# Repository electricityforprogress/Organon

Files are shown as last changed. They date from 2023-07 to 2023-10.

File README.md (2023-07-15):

# Organon
Biodata for Eurorack
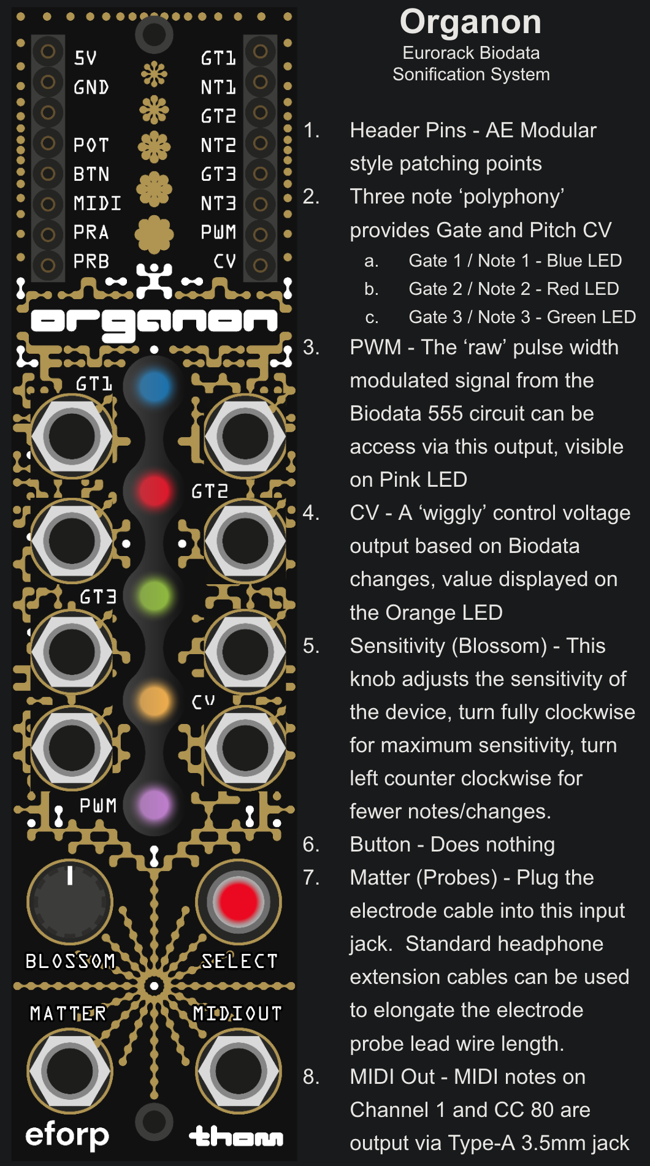
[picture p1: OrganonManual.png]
Organon Biodata Sonification System


This device can connect to the leaves of a plant and produces three pairs of Note CV and Gate signals, along with outputs for the 'raw' PWM Biodata square wave, a 'wiggly' CV output, and MIDI out!  The Organon comes with a set of snap electrode leads and three pairs of sticky pads. 
Using an Arduino Pro Micro 32u4, LMC555 timer, and a MC4728 Quad DAC this device was quite hard to find parts for until late 2023.

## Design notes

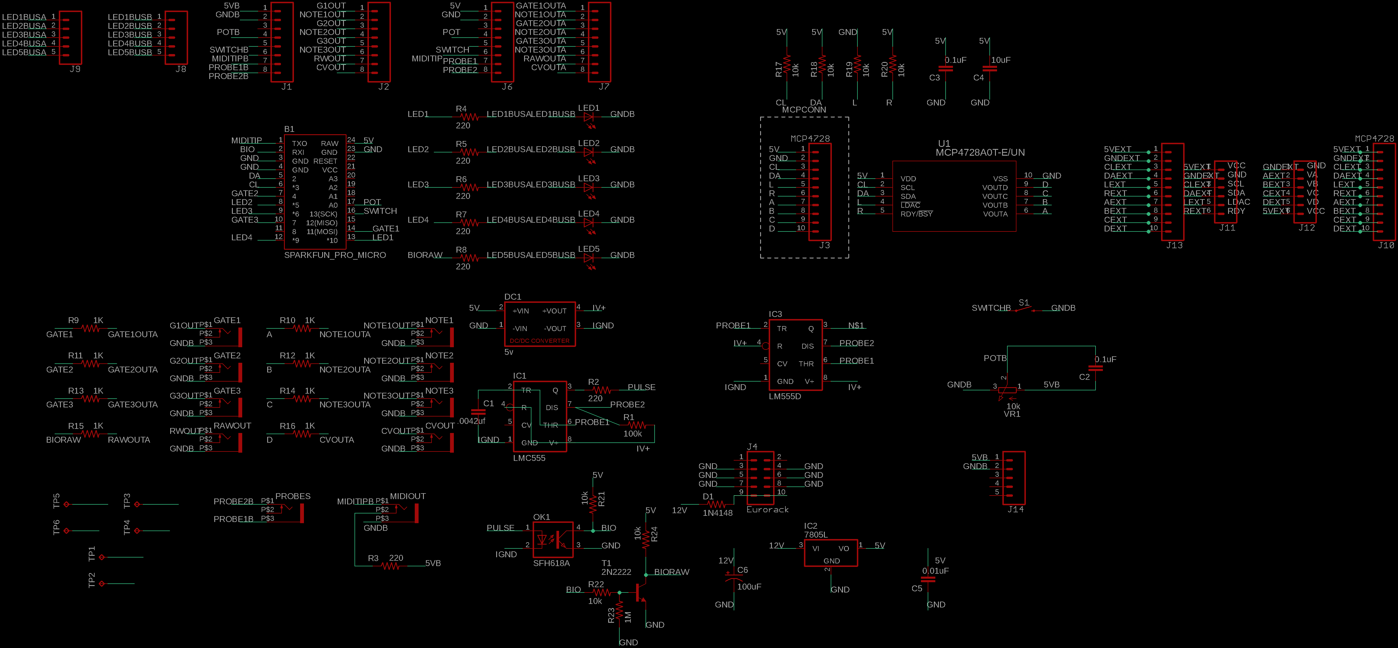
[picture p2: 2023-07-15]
Organon_Schematic.png

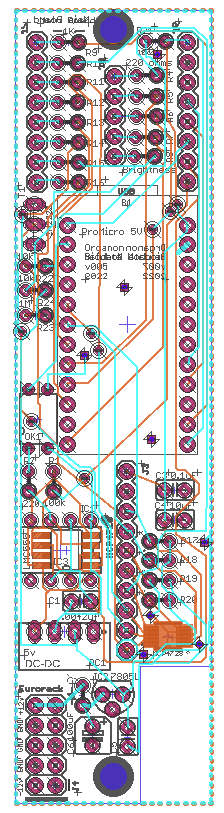
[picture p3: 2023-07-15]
BrainBoard007.png

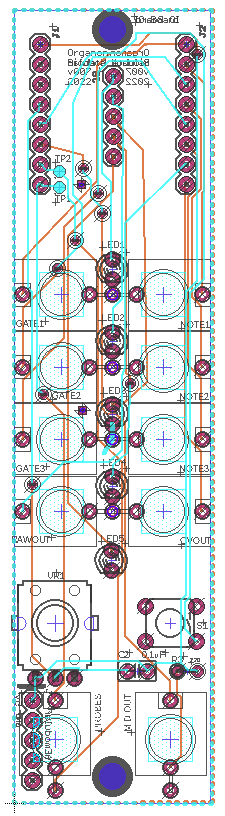
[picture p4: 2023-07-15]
IOBoard007.png

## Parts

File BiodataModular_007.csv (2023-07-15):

Part | Value | Device | Package | Description | MANUFACTURER_PART_NUMBER | MF | MPN | OC_FARNELL | OC_NEWARK | PROD_ID | SF_ID | SF_SKU | TP_SIGNAL_NAME | VENDOR
B1 | SPARKFUN_PRO_MICRO | SPARKFUN_PRO_MICRO | SPARKFUN_PRO_MICRO | SparkFun Pro Micro
C1 | .0042uf | C2.5/2 | C2.5-2 | CAPACITOR
C2 | 0.1uF | C2.5/2 | C2.5-2 | CAPACITOR
C3 | 0.1uF | C2.5/2 | C2.5-2 | CAPACITOR
C4 | 10uF | C2.5/2 | C2.5-2 | CAPACITOR
C5 | 0.01uF | C2.5/2 | C2.5-2 | CAPACITOR
C6 | 100uF | CPOL-USB45181A | B45181A | POLARIZED CAPACITOR, American symbol
CVOUT | WQP-PJ301M-12_JACK | WQP-PJ301M-12_JACK | WQP-PJ301M-12_JACK
D1 | 1N4148 | R-US_0204/2V | 0204V | RESISTOR, American symbol
DC1 | 5v | NME | NME | DC-DC CONVERTER |  | C & D TECHNOLOGIES, INC | NME1205D | 1021466 | 98B8198
GATE1 | WQP-PJ301M-12_JACK | WQP-PJ301M-12_JACK | WQP-PJ301M-12_JACK
GATE2 | WQP-PJ301M-12_JACK | WQP-PJ301M-12_JACK | WQP-PJ301M-12_JACK
GATE3 | WQP-PJ301M-12_JACK | WQP-PJ301M-12_JACK | WQP-PJ301M-12_JACK
IC1 | LMC555 | LM555N | DIL08 | TIMER
IC2 | 7805L | 7805L | TO92 | Positive VOLTAGE REGULATOR
IC3 | LM555D | LM555D | SO08 | TIMER
J1 |  | CONN_08";1X08" | Multi connection point. Often used as Generic Header-pin footprint for 0.1 inch spaced/style header connections |  |  |  |  |  | CONN-08438
J2 |  | CONN_08";1X08" | Multi connection point. Often used as Generic Header-pin footprint for 0.1 inch spaced/style header connections |  |  |  |  |  | CONN-08438
J3 | MCP4728 | CONN_10";1X10" | Multi connection point. Often used as Generic Header-pin footprint for 0.1 inch spaced/style header connections |  |  |  |  |  | CONN-11563
J4 | Eurorack | CONN_05X2PTH | 2X5 | Multi connection point. Often used as Generic Header-pin footprint for 0.1 inch spaced/style header connections |  |  |  |  |  | CONN-08499 | PRT-0778
J6 |  | CONN_08";1X08" | Multi connection point. Often used as Generic Header-pin footprint for 0.1 inch spaced/style header connections |  |  |  |  |  | CONN-08438
J7 |  | CONN_08";1X08" | Multi connection point. Often used as Generic Header-pin footprint for 0.1 inch spaced/style header connections |  |  |  |  |  | CONN-08438
J8 |  | CONN_05 | 1X05 | Multi connection point. Often used as Generic Header-pin footprint for 0.1 inch spaced/style header connections
J9 |  | CONN_05 | 1X05 | Multi connection point. Often used as Generic Header-pin footprint for 0.1 inch spaced/style header connections
J10 | MCP4728 | CONN_10";1X10" | Multi connection point. Often used as Generic Header-pin footprint for 0.1 inch spaced/style header connections |  |  |  |  |  | CONN-11563
J11 |  | CONN_06SILK_FEMALE_PTH | 1X06 | Multi connection point. Often used as Generic Header-pin footprint for 0.1 inch spaced/style header connections |  |  |  |  |  | CONN-08437
J12 |  | CONN_06SILK_FEMALE_PTH | 1X06 | Multi connection point. Often used as Generic Header-pin footprint for 0.1 inch spaced/style header connections |  |  |  |  |  | CONN-08437
J13 |  | CONN_10SMD_MALE | 1X10_SMD_MALE | Multi connection point. Often used as Generic Header-pin footprint for 0.1 inch spaced/style header connections |  |  |  |  |  | CONN-11291
J14 |  | CONN_05 | 1X05 | Multi connection point. Often used as Generic Header-pin footprint for 0.1 inch spaced/style header connections
LED1 |  | LED3MM | LED3MM | LED
LED2 |  | LED3MM | LED3MM | LED
LED3 |  | LED3MM | LED3MM | LED
LED4 |  | LED3MM | LED3MM | LED
LED5 |  | LED3MM | LED3MM | LED
MIDIOUT | WQP-PJ301M-12_JACK | WQP-PJ301M-12_JACK | WQP-PJ301M-12_JACK
NOTE1 | WQP-PJ301M-12_JACK | WQP-PJ301M-12_JACK | WQP-PJ301M-12_JACK
NOTE2 | WQP-PJ301M-12_JACK | WQP-PJ301M-12_JACK | WQP-PJ301M-12_JACK
NOTE3 | WQP-PJ301M-12_JACK | WQP-PJ301M-12_JACK | WQP-PJ301M-12_JACK
OK1 | SFH618A | SFH618A-5 | DIP4 | Optocoupler, Phototransistor Output, Low Input Current |  | VISHAY/TELEFUNKEN | SFH618A-5 | 1469593 | 59K0259
PROBES | WQP-PJ301M-12_JACK | WQP-PJ301M-12_JACK | WQP-PJ301M-12_JACK
R1 | 100k | R-US_0204/2V | 0204V | RESISTOR, American symbol
R2 | 220 | R-US_0204/2V | 0204V | RESISTOR, American symbol
R3 | 220 | R-US_0204/2V | 0204V | RESISTOR, American symbol
R4 | 220 | R-US_0204/2V | 0204V | RESISTOR, American symbol
R5 | 220 | R-US_0204/2V | 0204V | RESISTOR, American symbol
R6 | 220 | R-US_0204/2V | 0204V | RESISTOR, American symbol
R7 | 220 | R-US_0204/2V | 0204V | RESISTOR, American symbol
R8 | 220 | R-US_0204/2V | 0204V | RESISTOR, American symbol
R9 | 1K | R-US_0204/2V | 0204V | RESISTOR, American symbol
R10 | 1K | R-US_0204/2V | 0204V | RESISTOR, American symbol
R11 | 1K | R-US_0204/2V | 0204V | RESISTOR, American symbol
R12 | 1K | R-US_0204/2V | 0204V | RESISTOR, American symbol
R13 | 1K | R-US_0204/2V | 0204V | RESISTOR, American symbol
R14 | 1K | R-US_0204/2V | 0204V | RESISTOR, American symbol
R15 | 1K | R-US_0204/2V | 0204V | RESISTOR, American symbol
R16 | 1K | R-US_0204/2V | 0204V | RESISTOR, American symbol
R17 | 10k | R-US_0204/2V | 0204V | RESISTOR, American symbol
R18 | 10k | R-US_0204/2V | 0204V | RESISTOR, American symbol
R19 | 10k | R-US_0204/2V | 0204V | RESISTOR, American symbol
R20 | 10k | R-US_0204/2V | 0204V | RESISTOR, American symbol
R21 | 10k | R-US_0204/2V | 0204V | RESISTOR, American symbol
R22 | 10k | R-US_0204/2V | 0204V | RESISTOR, American symbol
R23 | 1M | R-US_0204/2V | 0204V | RESISTOR, American symbol
R24 | 10k | R-US_0204/2V | 0204V | RESISTOR, American symbol
RAWOUT | WQP-PJ301M-12_JACK | WQP-PJ301M-12_JACK | WQP-PJ301M-12_JACK
S1 | MOMENTARY-SWITCH-SPST-PTH-6.0MM | MOMENTARY-SWITCH-SPST-PTH-6.0MM | TACTILE_SWITCH_PTH_6.0MM | Momentary Switch (Pushbutton) - SPST |  |  |  |  |  | SWCH-08441 |  | COM-00097
T1 | 2N2222 | 2N2222 | TO92-EBC-OVAL | NPN TRANSISTOR
TP1 | TPB1,27 | TPB1,27 | B1,27 | Test pad
TP2 | TPB1,27 | TPB1,27 | B1,27 | Test pad
TP3 | TPB1,27 | TPB1,27 | B1,27 | Test pad
TP4 | TPB1,27 | TPB1,27 | B1,27 | Test pad
TP5 | TPB1,27 | TPB1,27 | B1,27 | Test pad
TP6 | TPB1,27 | TPB1,27 | B1,27 | Test pad
U1 | MCP4728A0T-E/UN | MCP4728A0T-E/UN | MSOP10_MC |  | MCP4728A0TEUN |  |  |  |  |  |  |  |  | Microchip
VR1 | 10k | EVUF2A | EVUF | 9 mm Square Rotary Potentiometers

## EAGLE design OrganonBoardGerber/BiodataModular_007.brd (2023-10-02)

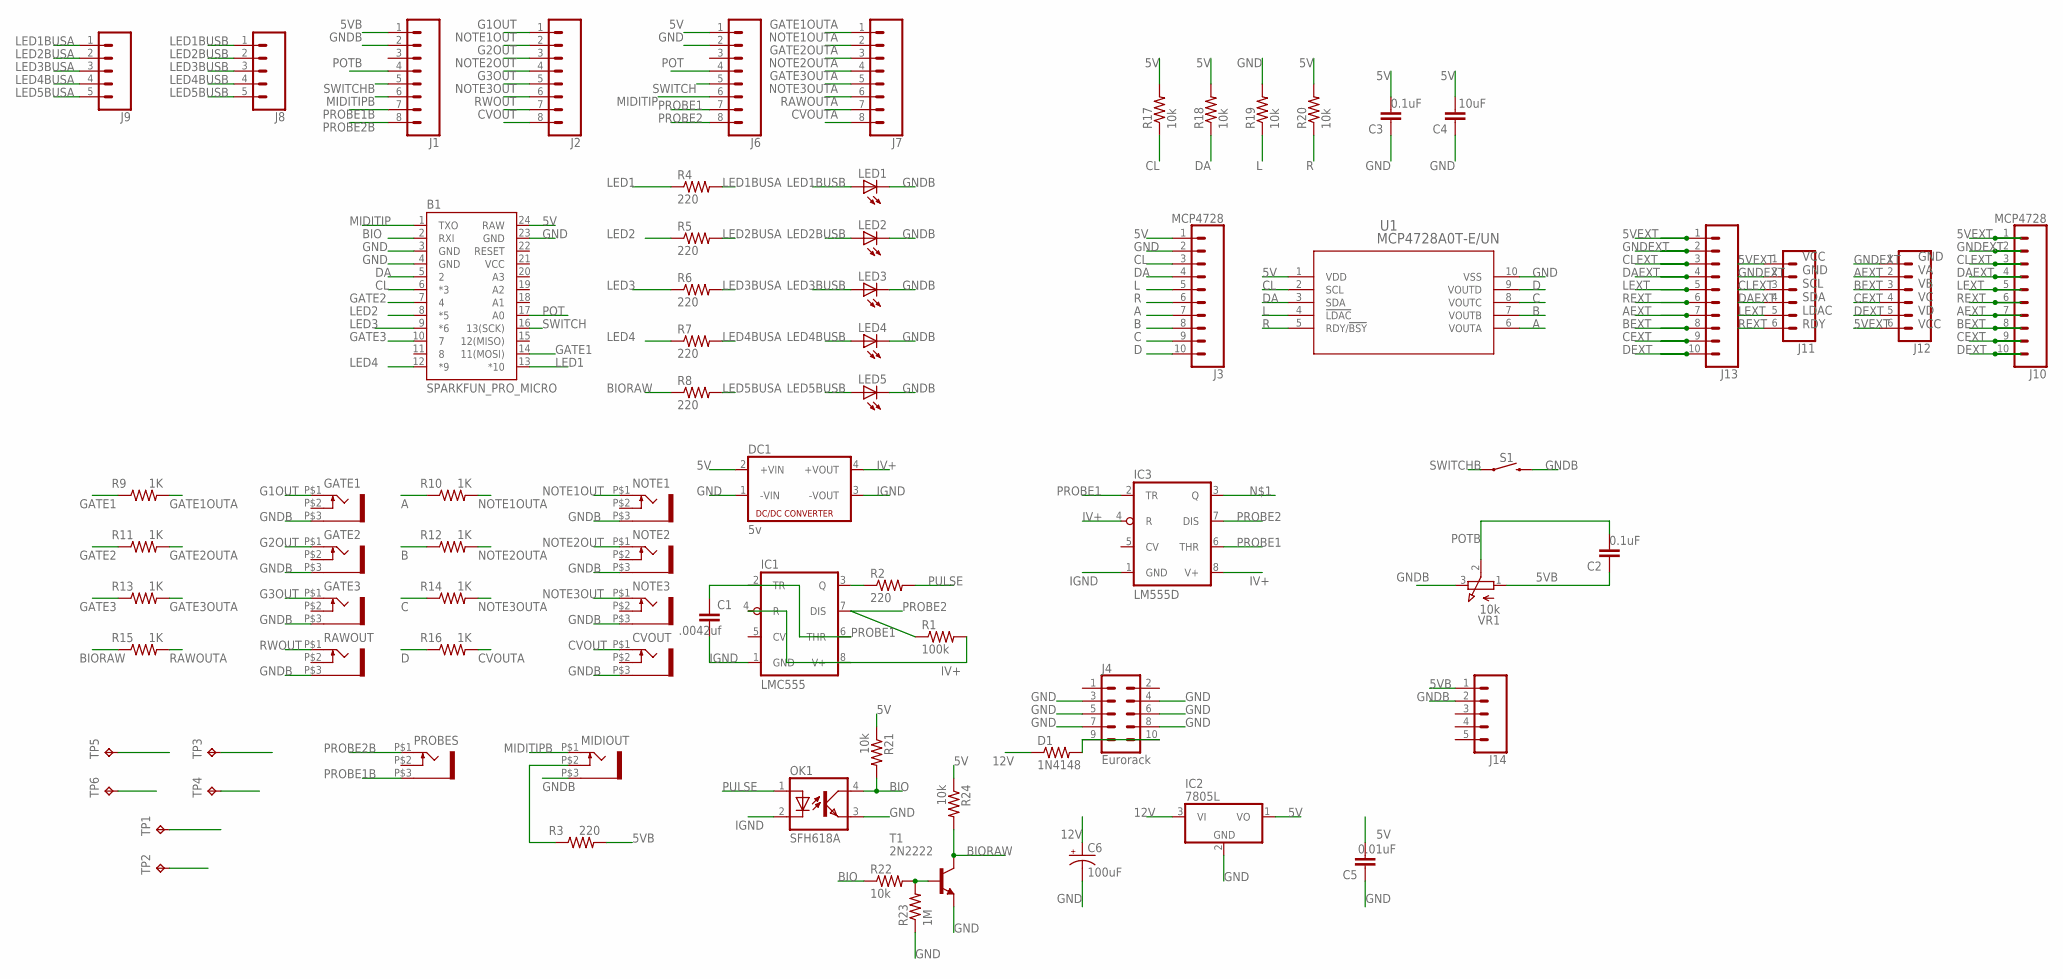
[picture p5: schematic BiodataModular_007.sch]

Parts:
B1: SPARKFUN_PRO_MICRO
C1: .0042uf; C2.5-2
C2, C3: 0.1uF; C2.5-2
C4: 10uF; C2.5-2
C5: 0.01uF; C2.5-2
C6: 100uF; B45181A
CVOUT: WQP-PJ301M-12_JACK
D1: 1N4148; 0204V
DC1: 5v; NME
GATE1, GATE2, GATE3: WQP-PJ301M-12_JACK
IC1: LMC555; DIL08
IC2: 7805L; TO92
IC3: LM555D; SO08
J1, J2, J6, J7: CONN_08"; 1X08
J3, J10: MCP4728; 1X10
J4: Eurorack; 2X5
J8, J9, J14: CONN_05; 1X05
J11, J12: CONN_06SILK_FEMALE_PTH; 1X06
J13: CONN_10SMD_MALE; 1X10_SMD_MALE
LED1, LED2, LED3, LED4, LED5: LED3MM
MIDIOUT: WQP-PJ301M-12_JACK
NOTE1, NOTE2, NOTE3: WQP-PJ301M-12_JACK
OK1: SFH618A; DIP4
PROBES: WQP-PJ301M-12_JACK
R1: 100k; 0204V
R2, R3, R4, R5, R6, R7, R8: 220; 0204V
R9, R10, R11, R12, R13, R14, R15, R16: 1K; 0204V
R17, R18, R19, R20, R21, R22, R24: 10k; 0204V
R23: 1M; 0204V
RAWOUT: WQP-PJ301M-12_JACK
S1: MOMENTARY-SWITCH-SPST-PTH-6.0MM; TACTILE_SWITCH_PTH_6.0MM
T1: 2N2222; TO92-EBC-OVAL
TP1, TP2, TP3, TP4, TP5, TP6: TPB1,27; B1,27
U1: MCP4728A0T-E/UN; MSOP10_MC
VR1: 10k; EVUF

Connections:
5V: B1.24 (RAW), C3.2, C4.2, C5.2, DC1.2 (+VIN), IC2.1 (VO), J3.1, J6.1, R17.2, R18.2, R20.2, R21.1, R24.1, U1.1 (VDD)
5VB: C2.1, J1.1, J14.1, R3.2, VR1.1 (A)
5VEXT: J10.1, J11.1, J12.6, J13.1
12V: C6.+, D1.1, IC2.3 (VI)
A: J3.7, R10.1, U1.6 (VOUTA)
AEXT: J10.7, J12.2, J13.7
B: J3.8, R12.1, U1.7 (VOUTB)
BEXT: J10.8, J12.3, J13.8
BIO: B1.2 (RXI), OK1.4 (COL), R21.2, R22.1
BIORAW: R8.1, R15.1, R24.2, T1.C
C: J3.9, R14.1, U1.8 (VOUTC)
CEXT: J10.9, J12.4, J13.9
CL: B1.6 (*3), J3.3, R17.1, U1.2 (SCL)
CLEXT: J10.3, J11.3, J13.3
CVOUT: CVOUT.P$1 (2), J2.8
CVOUTA: J7.8, R16.2
D: J3.10, R16.1, U1.9 (VOUTD)
DA: B1.5 (2), J3.4, R18.1, U1.3 (SDA)
DAEXT: J10.4, J11.4, J13.4
DEXT: J10.10, J12.5, J13.10
G1OUT: GATE1.P$1 (2), J2.1
G2OUT: GATE2.P$1 (2), J2.3
G3OUT: GATE3.P$1 (2), J2.5
GATE1: B1.14 (11(MOSI)), R9.1
GATE1OUTA: J7.1, R9.2
GATE2: B1.7 (4), R11.1
GATE2OUTA: J7.3, R11.2
GATE3: B1.10 (7), R13.1
GATE3OUTA: J7.5, R13.2
GND: B1.3 (GND), B1.4 (GND), B1.23 (GND), C3.1, C4.1, C5.1, C6.-, DC1.1 (-VIN), IC2.2 (GND), J3.2, J4.3, J4.4, J4.5, J4.6, J4.7, J4.8, J6.2, OK1.3 (EMIT), R19.2, R23.1, T1.E, U1.10 (VSS)
GNDB: CVOUT.P$3 (1), GATE1.P$3 (1), GATE2.P$3 (1), GATE3.P$3 (1), J1.2, J14.2, LED1.K (C), LED2.K (C), LED3.K (C), LED4.K (C), LED5.K (C), MIDIOUT.P$3 (1), NOTE1.P$3 (1), NOTE2.P$3 (1), NOTE3.P$3 (1), RAWOUT.P$3 (1), S1.3 (2), VR1.3 (E)
GNDEXT: J10.2, J11.2, J12.1, J13.2
IGND: C1.2, DC1.3 (-VOUT), IC1.1 (GND), IC3.1 (GND), OK1.2 (C)
IV+: DC1.4 (+VOUT), IC1.4 (R), IC1.8 (V+), IC3.4 (R), IC3.8 (V+), R1.2
L: J3.5, R19.1, U1.4 (!LDAC)
LED1: B1.13 (*10), R4.1
LED1BUSA: J9.1, R4.2
LED1BUSB: J8.1, LED1.A
LED2: B1.8 (*5), R5.1
LED2BUSA: J9.2, R5.2
LED2BUSB: J8.2, LED2.A
LED3: B1.9 (*6), R6.1
LED3BUSA: J9.3, R6.2
LED3BUSB: J8.3, LED3.A
LED4: B1.12 (*9), R7.1
LED4BUSA: J9.4, R7.2
LED4BUSB: J8.4, LED4.A
LED5BUSA: J9.5, R8.2
LED5BUSB: J8.5, LED5.A
LEXT: J10.5, J11.5, J13.5
MIDITIP: B1.1 (TXO), J6.6
MIDITIPB: J1.6, MIDIOUT.P$1 (2)
unnamed: IC1.3 (Q), IC3.3 (Q), R2.1
unnamed: MIDIOUT.P$2 (3), R3.1
unnamed: D1.2, J4.9, J4.10
unnamed: R22.2, R23.2, T1.B
NOTE1OUT: J2.2, NOTE1.P$1 (2)
NOTE1OUTA: J7.2, R10.2
NOTE2OUT: J2.4, NOTE2.P$1 (2)
NOTE2OUTA: J7.4, R12.2
NOTE3OUT: J2.6, NOTE3.P$1 (2)
NOTE3OUTA: J7.6, R14.2
POT: B1.17 (A0), J6.4
POTB: C2.2, J1.4, VR1.2 (S)
PROBE1: C1.1, IC1.2 (TR), IC1.6 (THR), IC3.2 (TR), IC3.6 (THR), J6.7
PROBE1B: J1.7, PROBES.P$3 (1), TP2.TP
PROBE1C: TP4.TP
PROBE1C1: TP6.TP
PROBE2: IC1.7 (DIS), IC3.7 (DIS), J6.8, R1.1
PROBE2B: J1.8, PROBES.P$1 (2), TP1.TP
PROBE2C: TP3.TP
PROBE2C1: TP5.TP
PULSE: OK1.1 (A), R2.2
R: J3.6, R20.1, U1.5 (RDY/!BSY)
RAWOUTA: J7.7, R15.2
REXT: J10.6, J11.6, J13.6
RWOUT: J2.7, RAWOUT.P$1 (2)
SWITCH: B1.16 (13(SCK)), J6.5
SWITCHB: J1.5, S1.1
VCC: B1.21 (VCC)

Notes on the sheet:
VCC GND SCL SDA LDAC RDY
GND VA VB VC VD VCC

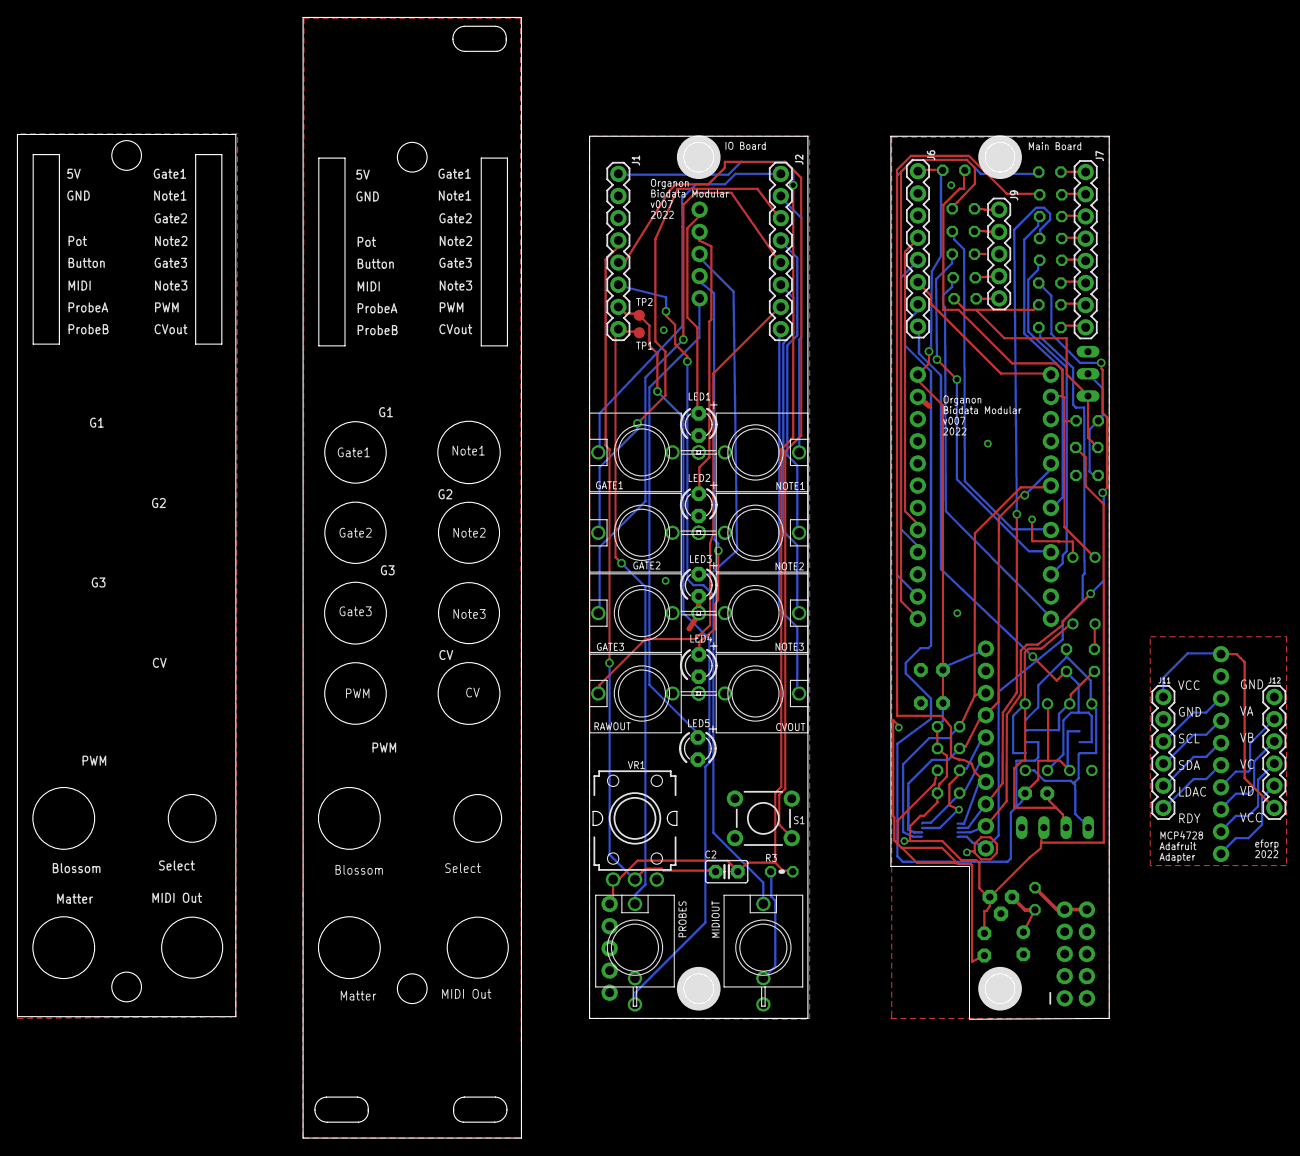
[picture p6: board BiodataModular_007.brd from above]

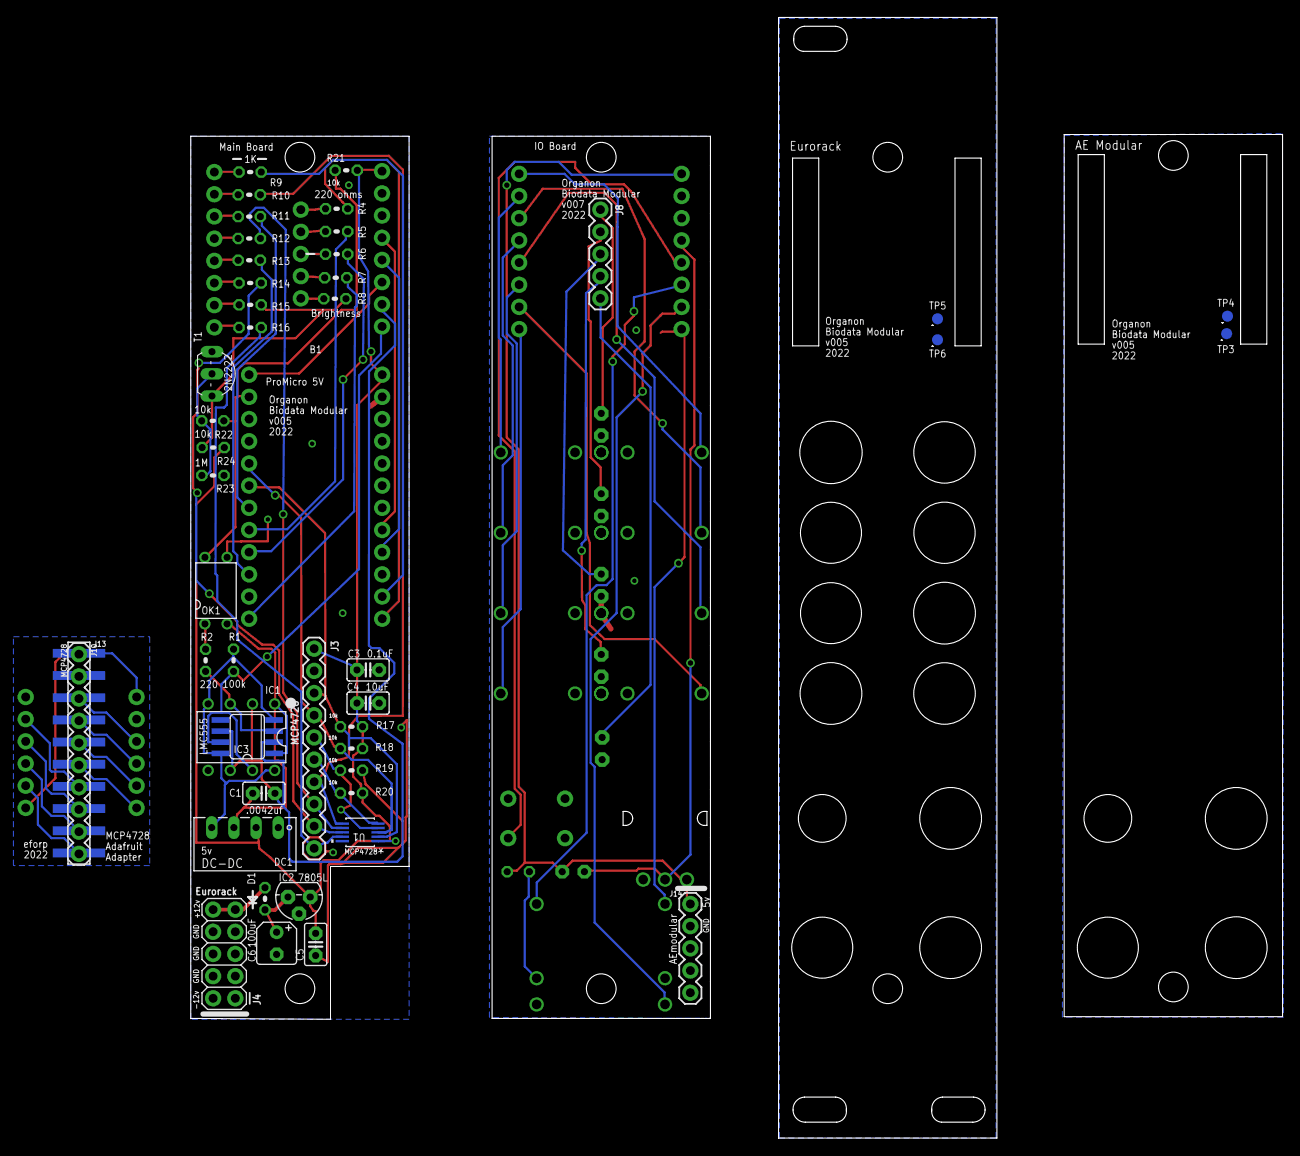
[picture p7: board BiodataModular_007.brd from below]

Board: 2 copper layers, 125.0 x 128.3 mm, 75 parts (47 on the bottom side), 75 nets.

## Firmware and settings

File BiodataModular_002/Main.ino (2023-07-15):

// -----------------------------------------------------------------------------
//
// -----------------------------------------------------------------------------
void setup() {

  if (debugSerial || rawSerial) Serial.begin(115200); // Serial baud for debugging and raw

 
      //load from EEPROM memory
  //    EEPROM.begin(EEPROM_SIZE);

 //DAC setup
  mcp.begin();
  
  //pinMode(buttonPin, INPUT_PULLUP); //button managed by PinButton
  pinMode(interruptPin, INPUT_PULLUP); //pulse input

  button.begin();

  pinMode(potPin, INPUT);

  pinMode(gate1Pin, OUTPUT);
  pinMode(gate2Pin, OUTPUT);
  pinMode(gate3Pin, OUTPUT);
  pinMode(rawBio, OUTPUT);
  pinMode(led1Pin, OUTPUT);
  pinMode(led2Pin, OUTPUT);
  pinMode(led3Pin, OUTPUT);
  pinMode(led4Pin, OUTPUT);

     //welcome message
     delay(150);
    if(debugSerial) Serial.println(); Serial.println();
    if(debugSerial) Serial.println(F("Welcome to Biodata Modular"));

    TXLED1; 
    RXLED1;

    //LED light show
    //turn them on
    for(byte i=0;i<ledCount;i++) {
        ledFaders[i].Setup(i);
        ledFaders[i].Set(ledFaders[i].maxBright,500*(i+1)); 
    }
    unsigned long prevMillis = millis();
    //let em fade up over time
    while(prevMillis+1000>millis()) {
        for(byte i=0;i<ledCount;i++) ledFaders[i].Update();
    }
    //turn them off
    for(byte i=0;i<ledCount;i++) {
        ledFaders[i].Set(0,500*(i+1)); 
    }
    //fade out over time
    prevMillis = millis();
    while(prevMillis+3000>millis()) {
        for(byte i=0;i<ledCount;i++) ledFaders[i].Update();
    }
   
//reset device device if button is held 'after light show'
 if(!digitalRead(buttonPin)) {
     if (debugSerial) Serial.println("Button Held at Bootup - Reset!");
     ledFaders[0].Set(255, 1000);
     ledFaders[0].Update();
     while(ledFaders[0].isRunning) {
        ledFaders[0].Update();
     }
     //reset memory - chromatic scale, channel 1, brightness 99%, MIDIcc 80
      //EEPROM.update(0, defScale); EEPROM.update(1, channel); EEPROM.update(2,99); EEPROM.update(3,80);
     // EEPROM.commit();
       //  maxBrightness = 99; //convert a two digit value to a float multiplier
       //  midiCC = 80; // change the MIDI CC wiggly channel
       //  channel = 1;  //declared at top
     //    scaleSelect = scalePenta;

     ledFaders[0].Set(0, 0); //does this set immediately?

}

//read from memory and load
//  byte scaleIndex = EEPROM.read(0);
//  byte midiChannel = EEPROM.read(1);
//  byte wifiPower = EEPROM.read(2);
//  byte blePower = EEPROM.read(3);
//  byte keybyte = EEPROM.read(4);
//  if(keybyte != 1) { //if not initialized first time - Scale,channel,wifi,bluetooth, key
//    //init for millersville
//    //EEPROM.write(0, 0); EEPROM.write(1, 1); EEPROM.write(2,1); EEPROM.write(3,0); EEPROM.write(4,1);
//     //normal init - ble ON, wifi OFF
//    //  EEPROM.update(0, defScale); EEPROM.update(1, channel); EEPROM.update(2,0); EEPROM.update(3,1); EEPROM.update(4,1);
//      //EEPROM.commit();
//      if (debugSerial) Serial.println("EEPROM Initialized - First time!");
//         scaleIndex = EEPROM.read(0);
//         midiChannel = EEPROM.read(1);
//         wifiPower = EEPROM.read(2);
//         blePower = EEPROM.read(3);
//  }
  
//  channel = midiChannel; //need two bytes to hold up to 16 channels!!
  
//                       if(scaleIndex == 0) scaleSelect = scaleChrom; 
//                       if(scaleIndex == 1) scaleSelect = scaleMinor; 
//                       if(scaleIndex == 2) scaleSelect = scaleMajor; 
//                       if(scaleIndex == 3) scaleSelect = scalePenta; 
//                       if(scaleIndex == 4) scaleSelect = scaleIndian; 
                       
  //   wifiMIDI = wifiPower;
  //   bleMIDI = blePower;
  

  if (serialMIDI)  setupSerialMIDI(); // MIDI hardware serial output
  
 // if (wifiMIDI)    setupWifi(); 
 // else { WiFi.disconnect(true); delay(1);   WiFi.mode(WIFI_OFF); delay(1);} //turn wifi radio off
 // if (bleMIDI)     bleSetup();

  //setup pulse input pin
  attachInterrupt(interruptPin, sample, RISING);  //begin sampling from interrupt
  //attachInterrupt(interruptPin, sampleFall, FALLING);  //begin sampling from interrupt

//for(byte i=0;i<ledCount;i++) { ledFaders[i].Set(0,2000); ledFaders[i].Update(); } //all fade off

} //end setup(){}

// -----------------------------------------------------------------------------
//
// -----------------------------------------------------------------------------
void loop() {

// turn off ugly red/green LEDs on proMicro Tx/Rx pins, 
// TXLED0 is ON - TXLED1 is Off
    TXLED1; 
    RXLED1;
    
  //manage time
  currentMillis = millis();
 // MIDI.read();
  
  //analyze data when the buffer is full
  if (sampleIndex >= samplesize)  {
    analyzeSample();
  }

  // Manage MIDI
  checkNote();  //turn off expired notes
  checkControl();  //update control value

  //update Raw output toggle
//  if(rawToggle!=prevToggle) {
//    if(rawToggle) { digitalWriteFast(rawBio, HIGH); digitalWriteFast(led4Pin, HIGH);}
//    else { digitalWriteFast(rawBio, LOW); digitalWriteFast(led4Pin, LOW); }
//    prevToggle = rawToggle;
//  }

  // Mange LEDs
  for(byte i=0;i<ledCount;i++) ledFaders[i].Update();
  
  //Manage pot and button
   checkKnob();  // updates threshold in main biodata mode
  // checkButton();

} //end loop(){}

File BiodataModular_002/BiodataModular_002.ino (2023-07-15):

//Electricity for Progress
// electricityforprogress.com
// store - Biodata - Modules - Custom
// **-----------------------------------------------------------------------------
/*
   Biodata Modular
   ProMicro 32u4 at 5v with
   mcp4728 Quad 12bit DAC
   555 timer Biodata input
   Three Gate, Three Note CV
   PWM Raw Out, Control CV
   MIDI Output
   Electrode Input

Features
1. Button and Knob handling
2. Menus - Note Scaling, MIDI Channel, Brightness, MIDI CC Change
3. Biodata input
4. Scaling Notes
5. Tuning/adjust? ?? tracking 0-5v, make it easy linear map(); or other algorithm

   
*/
// **-----------------------------------------------------------------------------

// DAC declaration Quad output
#include <Adafruit_MCP4728.h>
#include <Wire.h>

Adafruit_MCP4728 mcp;

//save settings to EEPROM for Scale, MIDI channel, poly or 'qy8 mode', bright,
#include <EEPROM.h>
#define EEPROM_SIZE 5 
  
//MIDI Note and Controls
const byte polyphony = 3; // 1; //mono  // number of notes to track at a given time

byte channel = 1; //MIDI channel can be set using menus

//******************************
//set scaled values, sorted array, first element scale length
//the whole scaling algorithm needs to be refactored ;)
//int scaleDiaMinor[]  = {7, 0, 2, 3, 5, 7, 8, 10};
int scalePenta[]  = {5, 0, 3, 5, 7, 9};
int scaleMajor[]  = {7, 0, 2, 4, 5, 7, 9, 11};
int scaleIndian[]  = {7, 0, 1, 1, 4, 5, 8, 10};
int scaleMinor[]  = {7, 0, 2, 3, 5, 7, 8, 10};
int scaleChrom[] = {13, 0, 1, 2, 3, 4, 5, 6, 7, 8, 9, 10, 11, 12};
     //enter the scale name here to use
int *scaleSelect = scaleChrom; //initialize scaling
byte defScale = 3; 
//   if(scaleIndex == 0) scaleSelect = scaleChrom; 
//   if(scaleIndex == 1) scaleSelect = scaleMinor; 
//   if(scaleIndex == 2) scaleSelect = scaleMajor; 
//   if(scaleIndex == 3) scaleSelect = scalePenta; 
//   if(scaleIndex == 4) scaleSelect = scaleIndian; 
int root = 0; //initialize for root
//*******************************

//Debug and MIDI output Settings ********
byte debugSerial = 1; //debugging serial messages
byte rawSerial = 1; // raw biodata stream via serial data
bool rawToggle = 0; //toggle for raw data output
bool prevToggle = 0; //actual value toggling

byte serialMIDI = 1; //write serial data to MIDI hardware output

byte midiMode = 0;  //change mode for serial, ble, wifi, usb

int noteMin = 36; //C2  - keyboard note minimum
int noteMax = 96; //C7  - keyboard note maximum
byte controlNumber = 80; //set to mappable control, low values may interfere with other soft synth controls!!

unsigned long rawSerialTime = 0;
int rawSerialDelay = 0;
// **************************************

#include <EEPROM.h>
#define EEPROM_SIZE 5 // scaleindex, midi channel, wifi, bluetooth, key

// I/O Pin declarations

#define interruptPin INT2  //biodata input pin
byte buttonPin = 15;   //for some reason it needed to be a byte, sigh
#define potPin A0
#define gate1Pin 16
#define gate2Pin 4
#define gate3Pin 7
#define rawBio 8  //not used 
#define led1Pin 10
#define led2Pin 5
#define led3Pin 6
#define led4Pin 9


//Potentiometer management
int knobValue = 0;
int knobPrev = 0;
unsigned long knobPrevTime = 0;
int knobTime = 300; //read pot every x milliseconds

// LED definition
#define ledCount 4
byte leds[ledCount] = {10,5,6,9};
byte maxBrightness = 50; //multipler for brightness
//8,5,1,8 -->  map(maxBrightness,0,100,
byte ledBrightness[ledCount] = {50,50,80,60};   //{80,50,10,80};  //adjust max per colour
//
unsigned long blinkTime = 0;
bool blinkToggle = 0;

//fading leds asynchronously
/*
 * pinNumber, maxBright,
 * currentLevel, destinationLevel, startTime, 
 * duration, stepSize, stepTime, isRunning
 * set stepSize as rate of fade based on maxBrightness and duration
 *      stepSize = duration/destinationLevel
 * if isRunning
 *   if currTime-startTime<duration //fade running
 *     if currTime=stepTime>stepSize
 *       stepTime=currTime
 *       if curr<dest, curr++
 *       if curr>dest, cur--
 *   else isRunning = FALSE //fade ended
 */
class samFader {
  
  public:
  byte pinNumber;
  byte espPWMchannel;
  int maxBright;
  int currentLevel = 0;
  int destinationLevel = 0;
  unsigned long startTime; //time at which a fade begins
  int duration = 0;
  unsigned long stepSize;  //computed duration across brightness 
  unsigned long stepTime; //last time a step was called
  bool isRunning = 0;

  samFader(byte pin, byte pwmChannel, byte maxB) {
    pinNumber=pin;
    espPWMchannel=pwmChannel;
    maxBright=maxB;
  }

  void Set(int dest, int dur) {
    startTime = millis();
    destinationLevel = dest;
    duration = dur;
    stepTime = 0;
    int difference = abs(destinationLevel - currentLevel);
    stepSize = duration/(difference+1);
    isRunning = 1;
    if(dur == 0) { // do it right away!
    //  ledcWrite(espPWMchannel, dest);  //this change is for ESP32 or other AVRs
      analogWrite(pinNumber,destinationLevel);
      isRunning = 0;
    }
  }
  
  void Update() {
    if(isRunning) {
      if(stepTime+stepSize<millis()) {
        //update to the next level
        if(currentLevel>destinationLevel) currentLevel--;
        if(currentLevel<destinationLevel) currentLevel++;
        //update variables for tracking
        stepTime = millis();
        //write brightness to LED
        //ledcWrite(espPWMchannel, currentLevel);
        analogWrite(pinNumber,currentLevel);
      }
      if(startTime+duration<millis()) {
     //   ledcWrite(espPWMchannel, destinationLevel);
        analogWrite(pinNumber,destinationLevel);
        isRunning = 0;
      }
    }

  }

  void Setup(byte chan) {
   // ledcSetup(chan,5000,13);    //ESP32 setup
   // ledcAttachPin(pinNumber,chan);  //ESP32 setup
   
  }
  
};

samFader ledFaders[] = {  samFader(leds[0],0,ledBrightness[0]),
                          samFader(leds[1],1,ledBrightness[1]),
                          samFader(leds[2],2,ledBrightness[2]),
                          samFader(leds[3],3,ledBrightness[3])
};



//Timing and tracking
unsigned long currentMillis = 0;
unsigned long prevMillis = 0;


//****** sample size sets the 'grain' of the detector
// a larger size will smooth over small variations
// a smaller size will excentuate small changes
const byte samplesize = 10; //set sample array size
const byte analysize = samplesize - 1;  //trim for analysis array,

volatile unsigned long microseconds; //sampling timer
volatile byte sampleIndex = 0;
volatile unsigned long samples[samplesize];

float threshold = 1.71; //threshold multiplier
float threshMin = 1.11; //1.61; //scaling threshold min
float threshMax = 4.01  ; //scaling threshold max
float prevThreshold = 0;



typedef struct _MIDImessage { //build structure for Note and Control MIDImessages
  unsigned int type;
  int value;
  int velocity;
  long duration;
  long period;
  int channel;
}
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

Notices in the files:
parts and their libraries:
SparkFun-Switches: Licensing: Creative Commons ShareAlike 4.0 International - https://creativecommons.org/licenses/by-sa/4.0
